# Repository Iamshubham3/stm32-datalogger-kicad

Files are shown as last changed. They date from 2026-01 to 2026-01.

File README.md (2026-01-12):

# STM32 Datalogger PCB (KiCad)

This project started from an STM32 dev-board baseline and was extended into a datalogger-oriented PCB.
Main additions: external EEPROM (I2C), LSE crystal for RTC accuracy, and backup cell support to keep RTC running when main power is off.

## What I changed (conversion summary)
- Added I2C EEPROM block (address pins, decoupling, write-protect as applicable)
- Added I2C pull-up resistors sized for 3.3V logic
- Added 32.768 MHz crystal (LSE) for stable RTC timekeeping
- Added backup power cell circuitry (VBAT/RTC domain support)
- Updated connectors/test points for logging/debug (UART/I2C as required)
- Verified ERC/DRC and updated net labels + power domains

## Datalogger use-case
- Logs sensor/measurement data via I2C/SPI/UART peripherals
- Stores samples into EEPROM and timestamps using RTC (battery-backed)

## Tools
- KiCad v8

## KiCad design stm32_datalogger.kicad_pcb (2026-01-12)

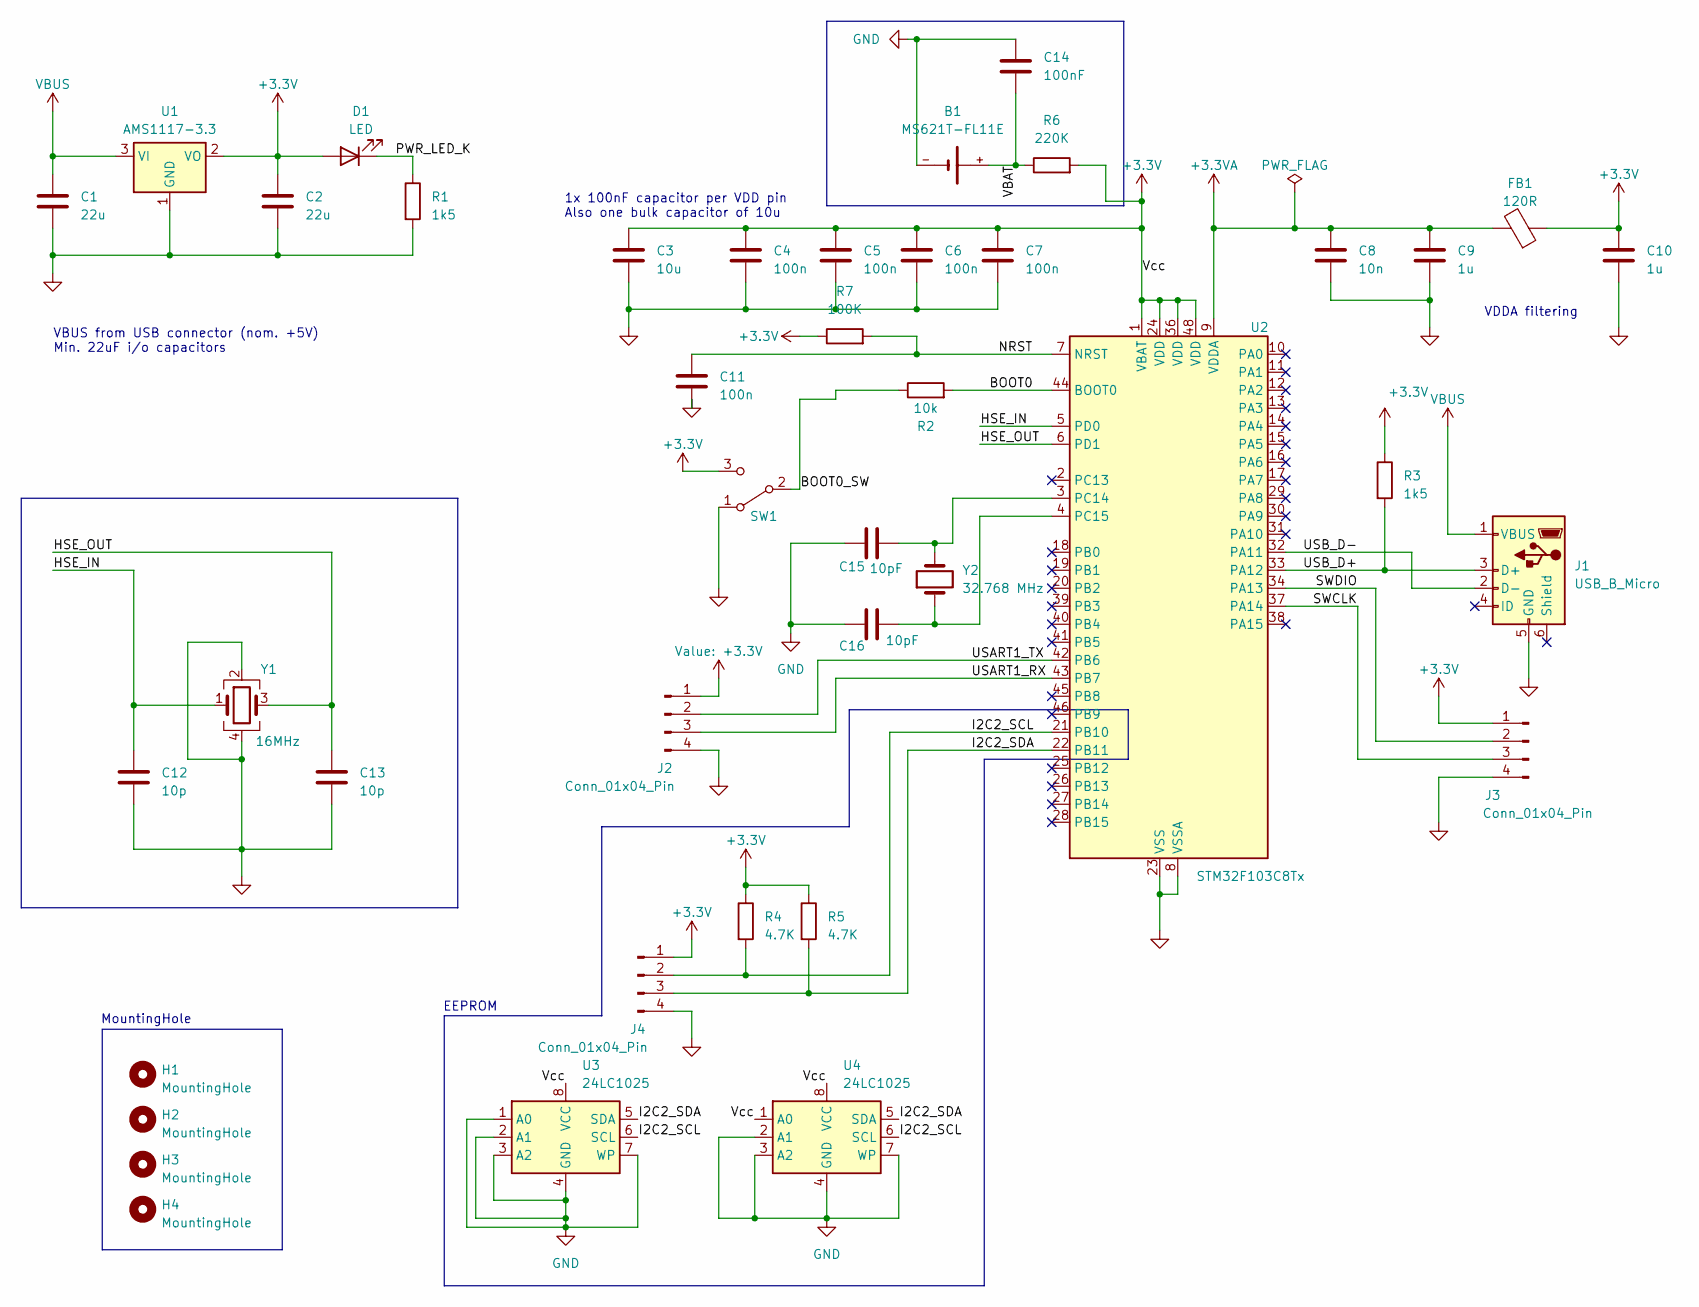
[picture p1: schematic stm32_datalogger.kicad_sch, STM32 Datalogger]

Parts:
B1: MS621T-FL11E; MS621FE-FL11E
C1, C2: 22u; C_0805_2012Metric
C3: 10u; C_0603_1608Metric
C4, C5, C6, C7, C11: 100n; C_0402_1005Metric
C8: 10n; C_0402_1005Metric
C9, C10: 1u; C_0402_1005Metric
C12, C13: 10p; C_0402_1005Metric
C14: 100nF; C_0402_1005Metric
C15, C16: 10pF; C_0402_1005Metric
D1: LED; LED_0603_1608Metric
FB1: 120R; L_0603_1608Metric
H1, H2, H3, H4: MountingHole; MountingHole_2.2mm_M2
J1: USB_B_Micro; USB_Micro-B_Wuerth_629105150521
J2, J3, J4: Conn_01x04_Pin; PinHeader_1x04_P2.54mm_Vertical
R1, R3: 1k5; R_0402_1005Metric
R2: 10k; R_0402_1005Metric
R4, R5: 4.7K; R_0402_1005Metric
R6: 220K; R_0402_1005Metric
R7: 100K; R_0402_1005Metric
SW1: SW_SPDT; SW_SPDT_PCM12
U1: AMS1117-3.3; SOT-223-3_TabPin2
U2: STM32F103C8Tx; LQFP-48_7x7mm_P0.5mm
U3, U4: 24LC1025; SOIC-8_3.9x4.9mm_P1.27mm
Y1: 16MHz; Crystal_SMD_3225-4Pin_3.2x2.5mm
Y2: 32.768 MHz; Crystal_SMD_3215-2Pin_3.2x1.5mm

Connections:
+3.3V: C2.1, C3.1, C4.1, C5.1, C6.1, C7.1, C10.1, D1.2 (A), FB1.1, J2.1, J3.1, J4.1, R3.1, R4.1, R5.1, R6.2, R7.1, SW1.3 (C), U1.2 (VO), U2.1 (VBAT), U2.24 (VDD), U2.36 (VDD), U2.48 (VDD), U3.8 (VCC), U4.1 (A0), U4.8 (VCC)
+3.3VA: C8.1, C9.1, FB1.2, U2.9 (VDDA)
/BOOT0: R2.2, U2.44 (BOOT0)
/BOOT0_SW: R2.1, SW1.2 (B)
/HSE_IN: C12.1, U2.5 (PD0), Y1.1
/HSE_OUT: C13.1, U2.6 (PD1), Y1.3
/I2C2_SCL: J4.2, R4.2, U2.21 (PB10), U3.6 (SCL), U4.6 (SCL)
/I2C2_SDA: J4.3, R5.2, U2.22 (PB11), U3.5 (SDA), U4.5 (SDA)
/NRST: C11.1, R7.2, U2.7 (NRST)
/PWR_LED_K: D1.1 (K), R1.1
/SWCLK: J3.3, U2.37 (PA14)
/SWDIO: J3.2, U2.34 (PA13)
/USART1_RX: J2.3, U2.43 (PB7)
/USART1_TX: J2.2, U2.42 (PB6)
/USB_D+: J1.3 (D+), R3.2, U2.33 (PA12)
/USB_D-: J1.2 (D-), U2.32 (PA11)
/VBAT: B1.+, C14.2, R6.1
GND: B1.-, C1.2, C2.2, C3.2, C4.2, C5.2, C6.2, C7.2, C8.2, C9.2, C10.2, C11.2, C12.2, C13.2, C14.1, C15.1, C16.1, J1.5 (GND), J2.4, J3.4, J4.4, R1.2, SW1.1 (A), U1.1 (GND), U2.8 (VSSA), U2.23 (VSS), U2.35 (VSS), U2.47 (VSS), U3.1 (A0), U3.2 (A1), U3.3 (A2), U3.4 (GND), U3.7 (WP), U4.2 (A1), U4.3 (A2), U4.4 (GND), U4.7 (WP), Y1.2, Y1.4
unnamed: C15.2, U2.3 (PC14), Y2.2
unnamed: C16.2, U2.4 (PC15), Y2.1
VBUS: C1.1, J1.1 (VBUS), U1.3 (VI)

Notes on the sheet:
1x 100nF capacitor per VDD pin Also one bulk capacitor of 10u
VBUS from USB connector (nom. +5V) Min. 22uF i/o capacitors
EEPROM
VDDA filtering
MountingHole

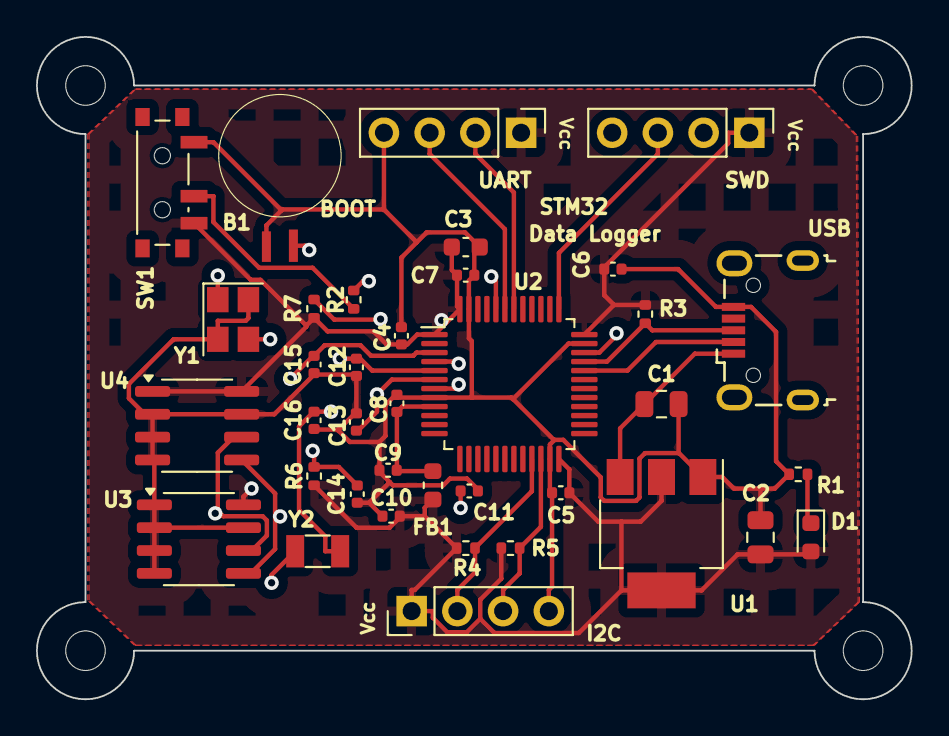
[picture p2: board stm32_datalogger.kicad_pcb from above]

Board: 4 copper layers, 48.6 x 36.8 mm, 41 parts (0 on the bottom side), 21 nets.

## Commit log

2026-01-12 Initial commit: KiCad STM32 datalogger project
    [629105150521 (rev1).stp, stm32_board.kicad_pcb, stm32_board.kicad_sch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]
2026-01-12 Initialize README with project details and usage
    Added project overview and conversion summary for STM32 Datalogger PCB.
2026-01-12 Update KiCad version in README
